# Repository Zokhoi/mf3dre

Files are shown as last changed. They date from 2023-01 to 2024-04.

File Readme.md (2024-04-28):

# Midi Fighter 3D Reverse Engineering
This repo holds the reverse engineered schematics and PCB design that should hopefully be functionally identical to the DJTechTools Midi Fighter 3D. This was done in the effort of creating functional firmware for the MF3D, as DJTechTools has shared or open sourced every Midi Fighter firmware except for MF3D.

The repository requires KiCAD v7.

However, there are also some components that I am not very certain about, which I hope would be uncovered as time goes by. In specific, the list of items are:
* the model of the LEDs
  * 4 white LEDs for bank buttons on top
  * 32 non-addressable RGB LEDs for arcade buttons

## Other details
Here are some of the other details that I have noticed while performing the reverse engineering.
* The button and RGB LED footprints are angled at 15 degrees.
* The pull up resistors R11 and R12 has pads on the PCB but are missing from the actual product. Maybe the chip doesn't actually need them?
* The through hole tactile switches SW23 and SW24 are not installed in the actual product. Presumably you can mount them on either side of the PCB.
* Both pin headers are not installed in the actual product.
* D17 is a chip with 5 internal diodes, and D18-21 are missing in the schematic, so the diodes in the chip were probably individually numbered in the original design.
* Resistor networks R5-7 are probably [CTS Electronic Components 746X101103JP](https://www.digikey.com/en/products/detail/cts-resistor-products/746X101103JP/1118406).
* The arcade button footprint has a test pad on the pulled up side, but I did not include it in the recreated footprint.
* The mounting screws are probably M3 screws.

In an email exchange with DJTT, they have stated that the magnometer IST8308 has been replaced by accelerometer MMA8453Q, but [both of these chips are present](./img/i2c%20cluster.png) on my board. In addition, the circuitry around IST8308 (U11) does not seem to correspond to the application circuit given in its datasheet.

## Previews
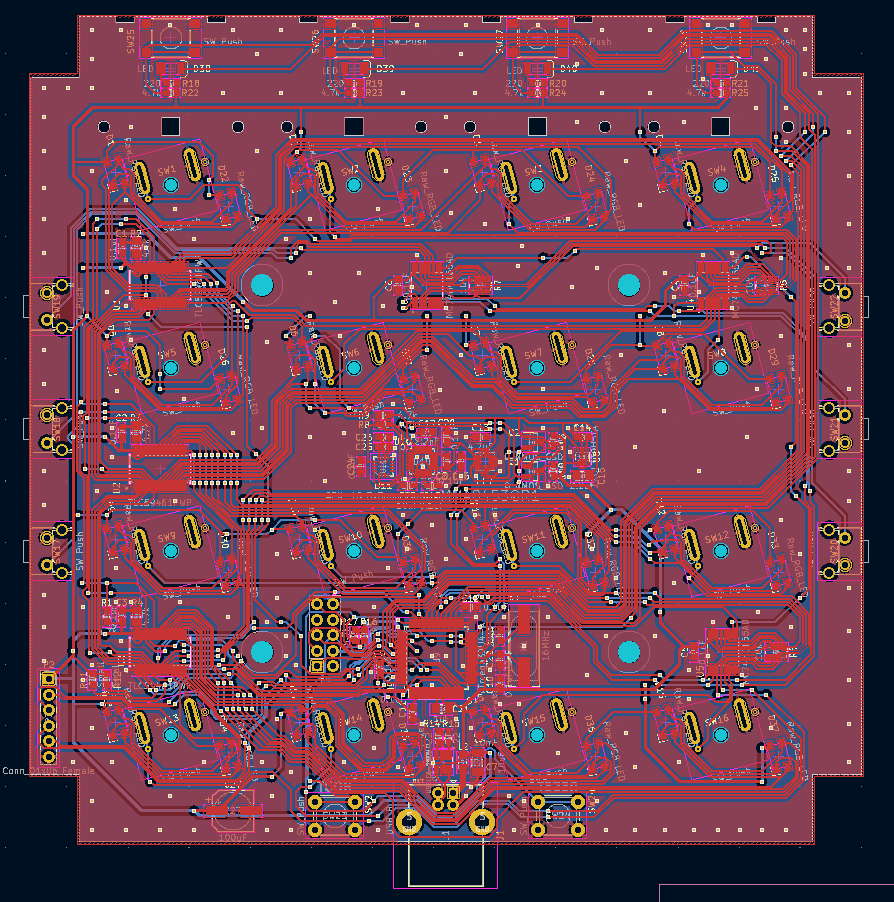
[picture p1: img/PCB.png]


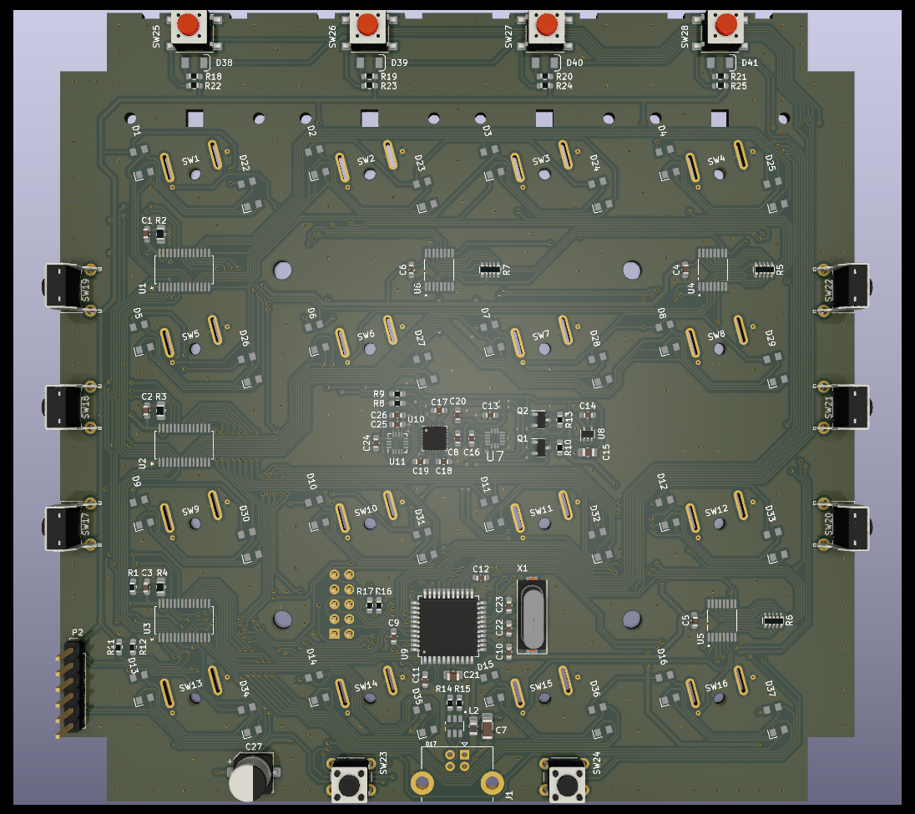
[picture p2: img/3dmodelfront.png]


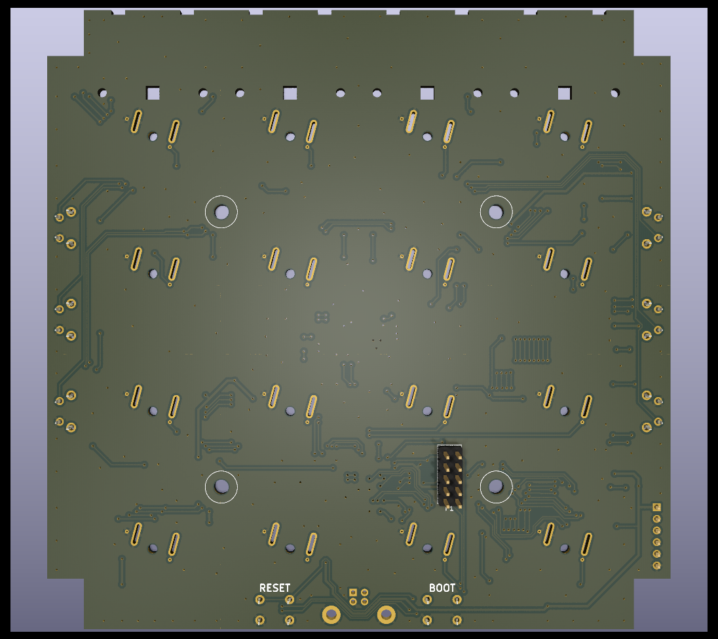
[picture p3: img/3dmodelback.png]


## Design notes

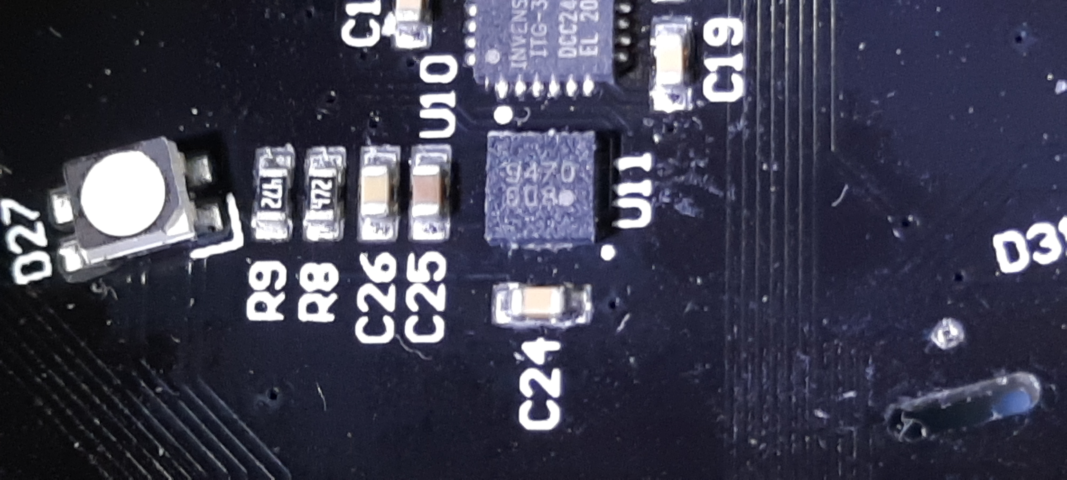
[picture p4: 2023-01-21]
img/U11.jpg

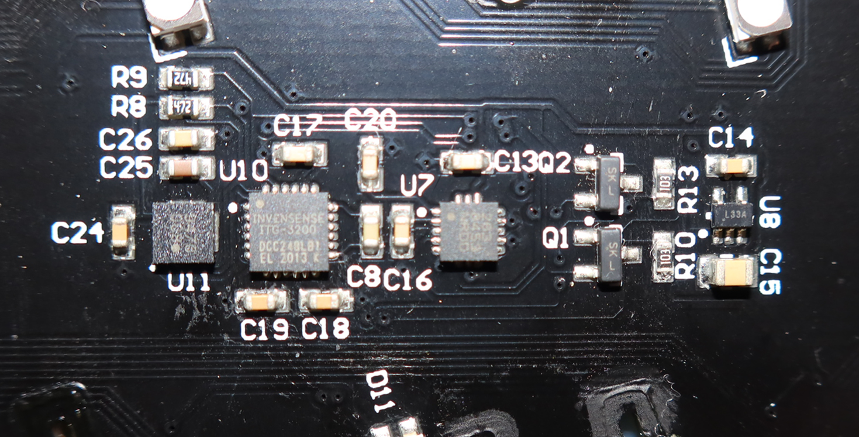
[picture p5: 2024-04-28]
img/i2c cluster.png

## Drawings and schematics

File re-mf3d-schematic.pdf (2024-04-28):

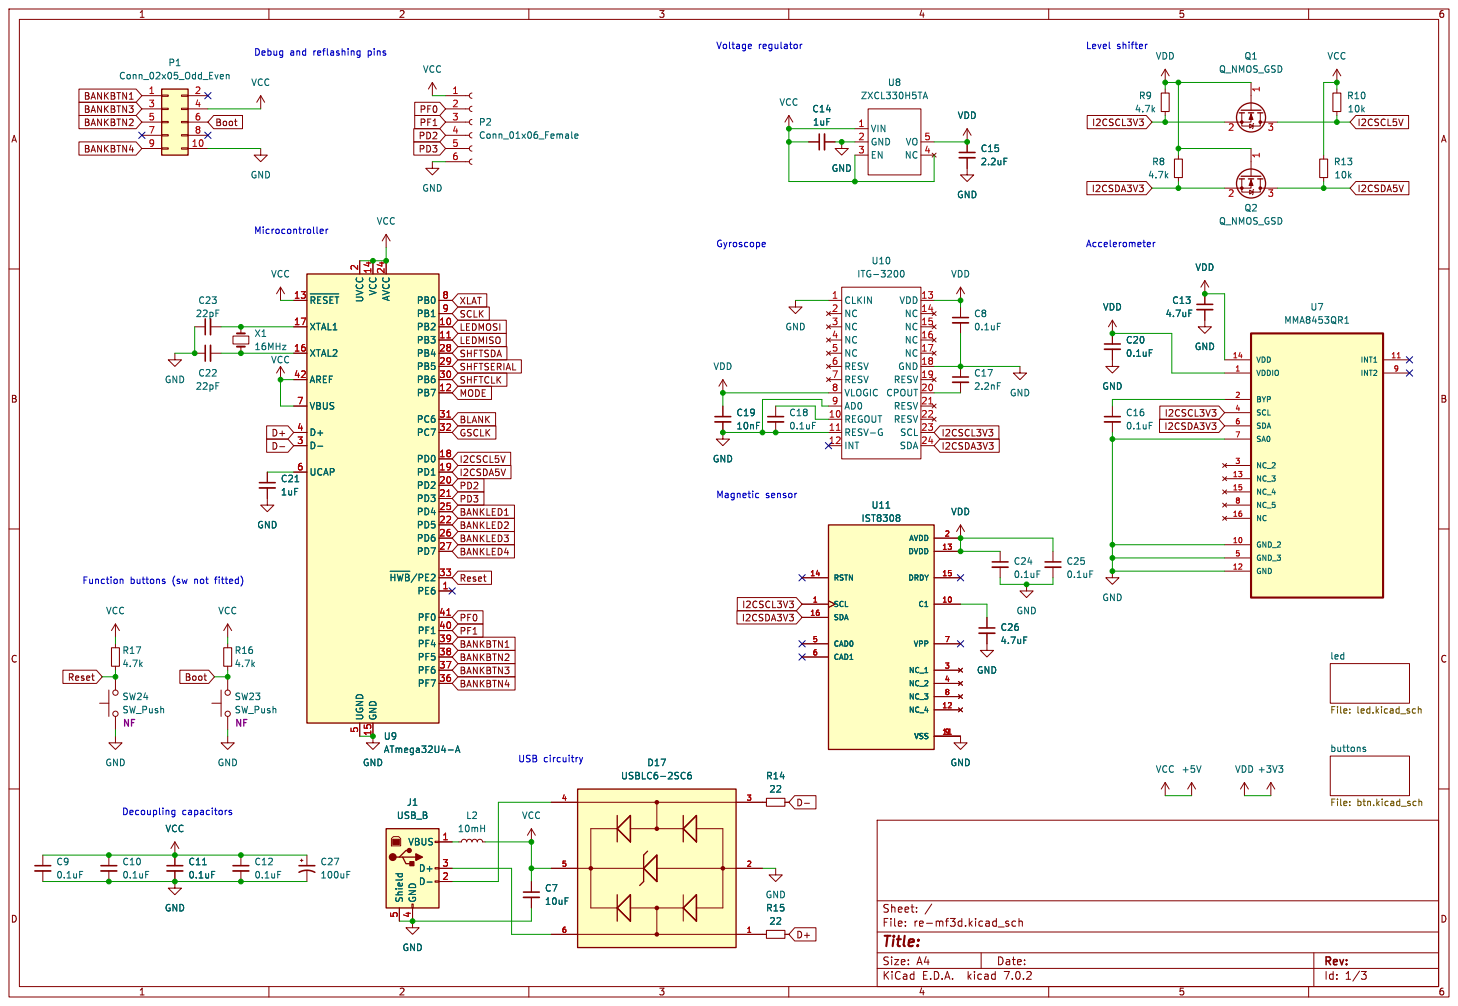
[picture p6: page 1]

Magnetic sensor USB circuitry

Id: 1/3 Title: File: re-mf3d.kicad_sch Sheet: /

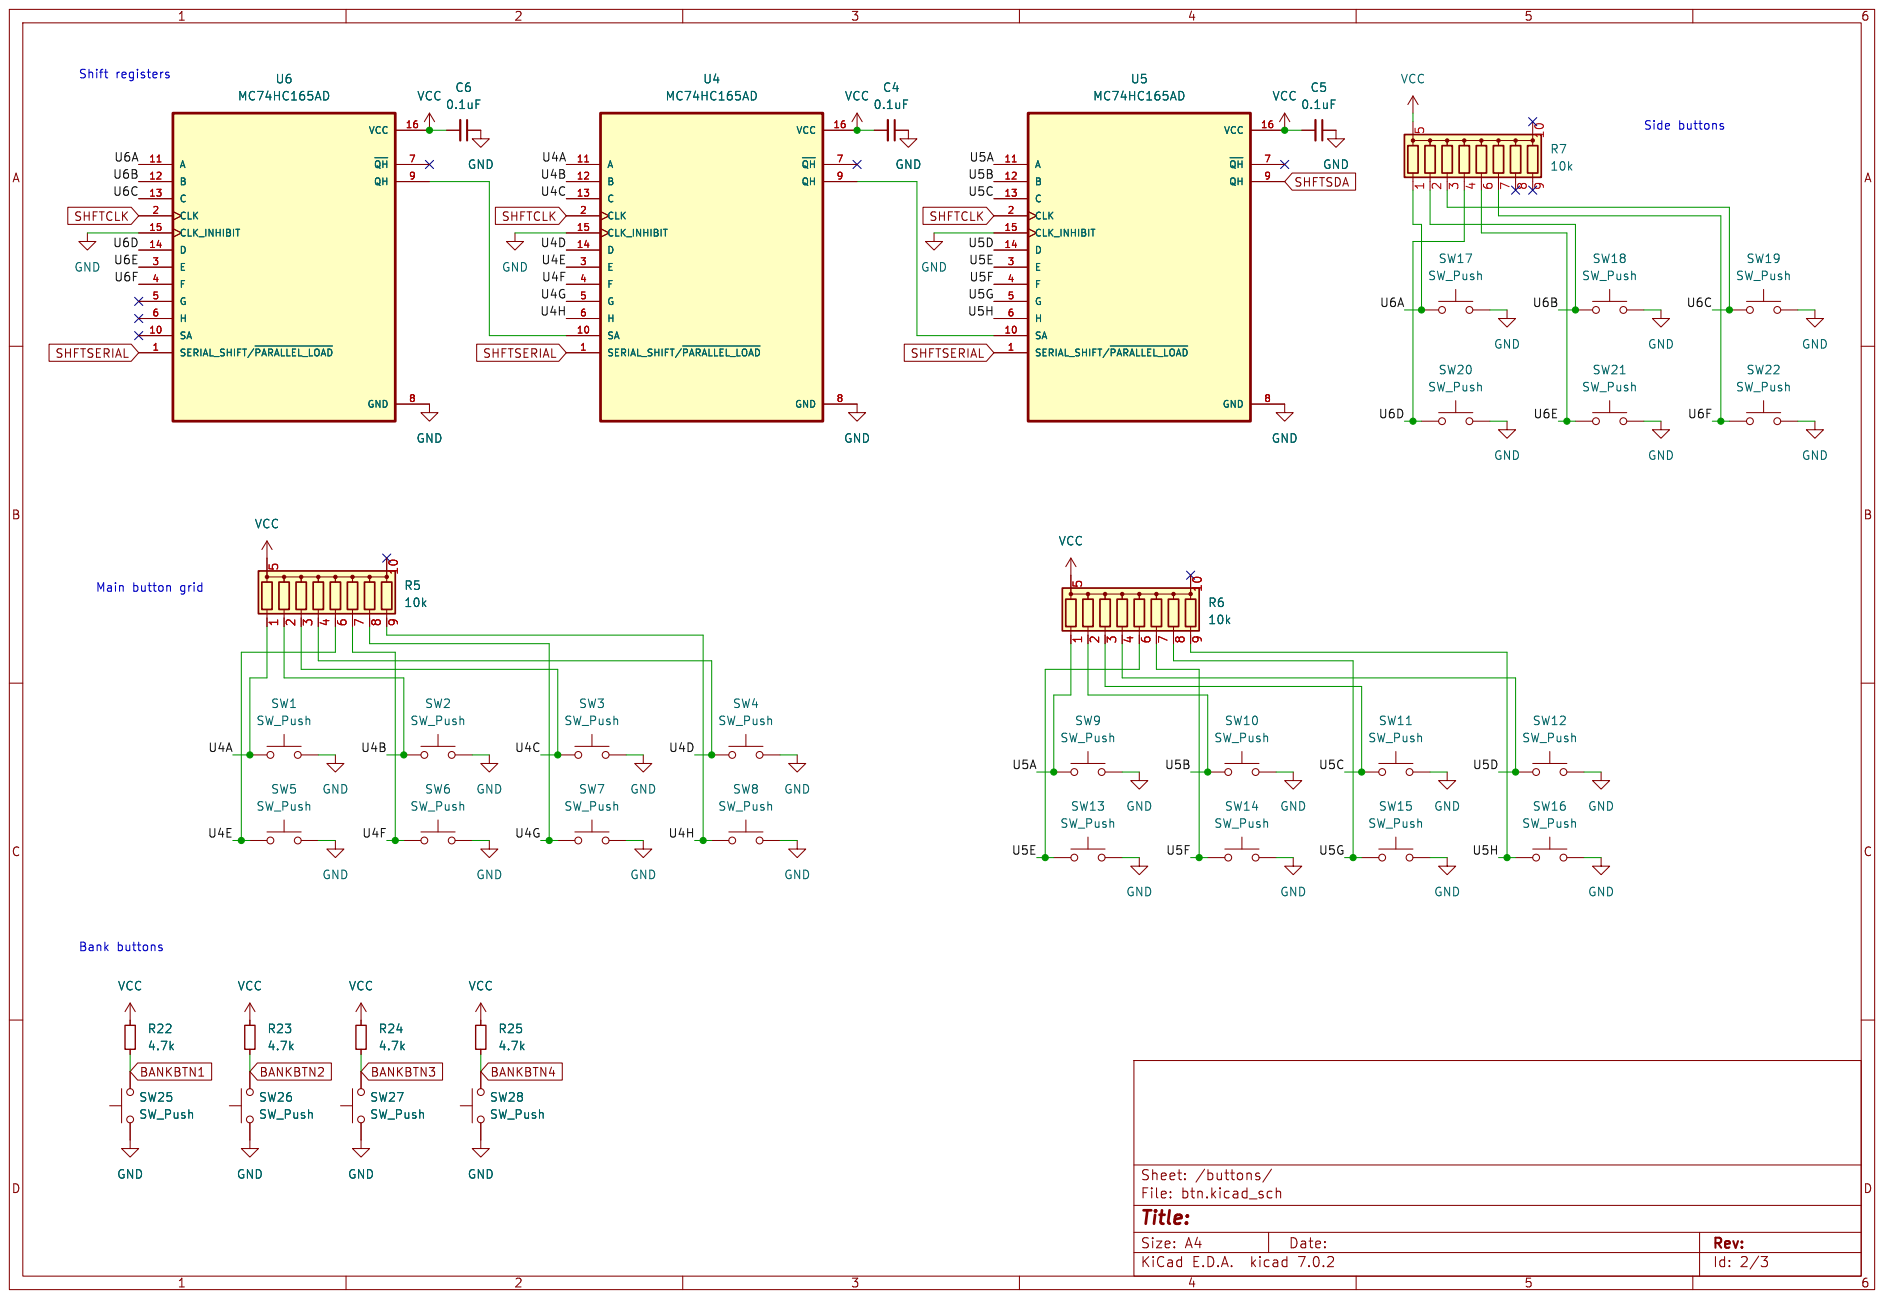
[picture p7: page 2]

Shift registers Main button grid VCC

Side buttons Bank buttons

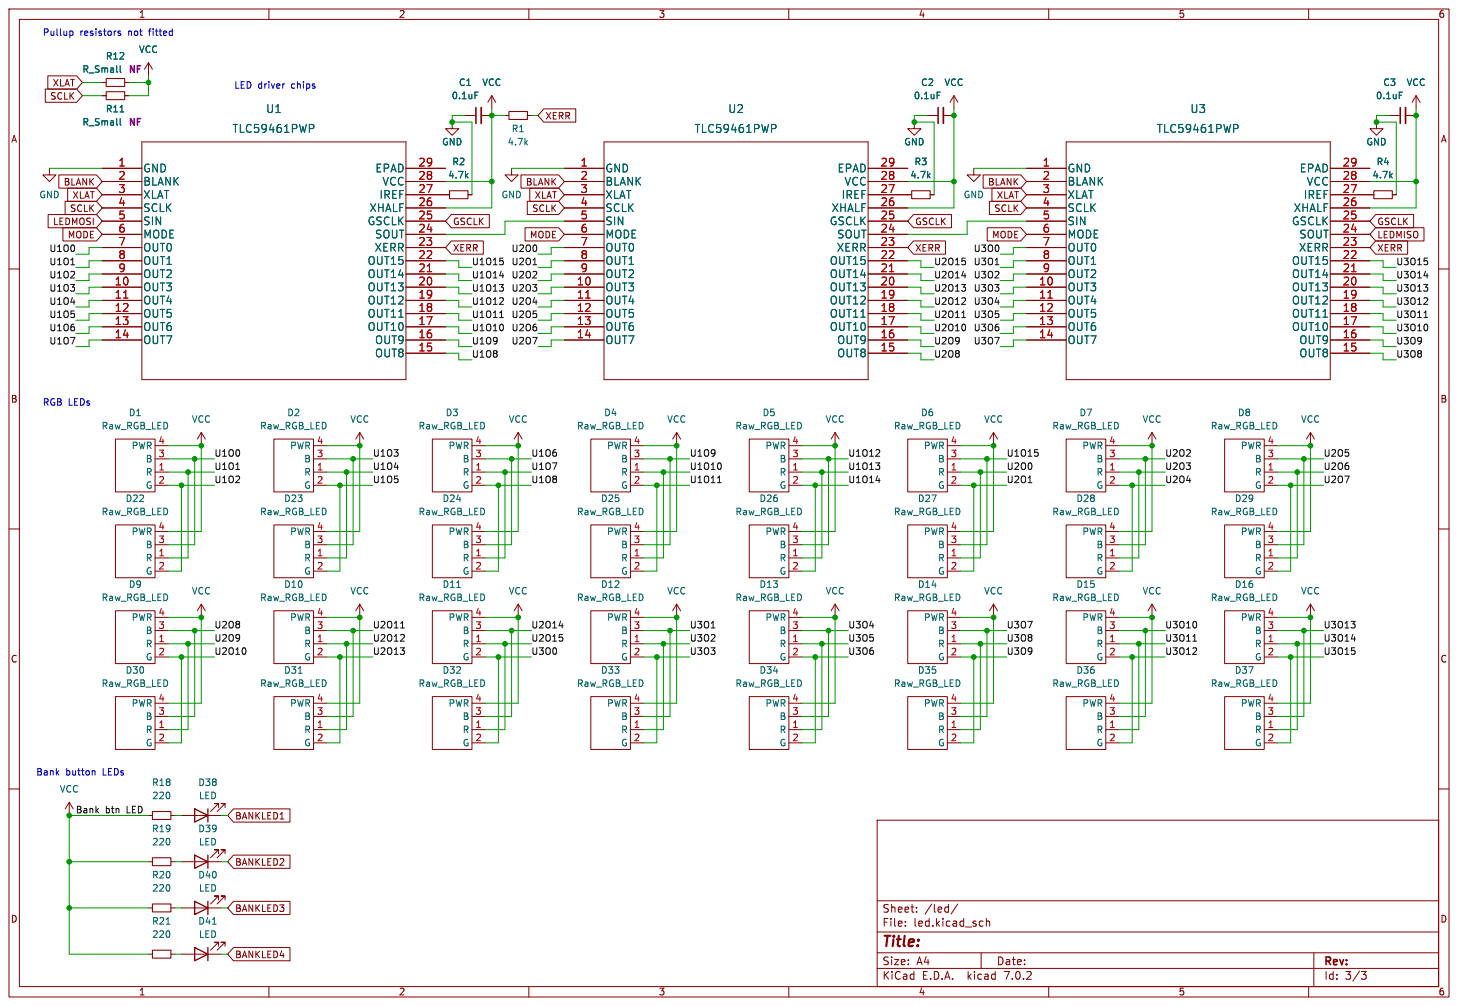
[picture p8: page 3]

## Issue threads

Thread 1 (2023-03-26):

Can you upload bootloader and firmware on it?

DRCRecoveryData, 2023-03-26:
Hi,

If we made new pcb does it work on original firmware?

Zokhoi, 2023-03-27:
That's what I'm hoping to achieve yes. However as the README has mentioned there are still some issues that can't be overlooked, even if you could get all the exact components right by transferring them from a working board. In specific, the issues are:
* the chip U11 and its related traces
* the footprint for the resistor networks R5, R6 and R7
Other than these, if you source new components, the capacitors and inductor values and led models are a problem too.

DRCRecoveryData, 2024-04-05:
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

Can you open request to djtechtools:

support@djtechtools.com

to get the stock firmware upload file of midi fighter 3d via icsp pinout?

i have request them like this:

Hi,

I have set fuses wrong of midi fighter 64 via icsp port

I use avrduress and forgot to set fuses to 00 so can't detect again the atmega32u4

Should i buy new atmega32u4 chip and flash new bootloader and firmware?

I need your guide and bootloader & firmware & fuses bit value setting
to repair it

and they sent firmware file and tutorial upload by:

Setup
1. Instal WinAVR (avrdude)
2. Instal Drivers for the USBTiny Pocket Programmer
3. Set slide switch on the USB Pocket Programmer to "No Power"
4. Open Command Prompt, type "avrdude". You should see the version and the options listed

Uploading HEX
1. Connect the MF64_V3 PCB to the PC with a USB cable
2. Connect the USB Pocket Programmer as shown in the picture
3. Make sure all the programing pins are in contact with the PCB. You can put a little pressure on the programmer cable with your thumb to ensure a good connection.
4. Double click "AVRDude - Upload HEX.bat"
5. HEX will upload, LED's will cycle RED, GREEN, BLUE. All LED's should be lit, on all colors.
6. Remove the 6 pin programming header
7. Remove the MF64_V3 PCB USB connection

Possible Errors:
1. If USBTiny cannot be found when uploading HEX, unplug and replug the USBTiny Pocket Programmer

maybe you can help to request they sent stock file :))

Zokhoi, 2024-04-05:
If you have midifighter utility installed, I think you can find the mf3d firmware binary in the internal files.

I have previously sent a support ticket asking for mf3d firmware source code, they replied they did not have plans to release the source code at the time though.

DRCRecoveryData, 2024-04-05:
> If you have midifighter utility installed, I think you can find the mf3d firmware binary in the internal files.
>
> I have previously sent a support ticket asking for mf3d firmware source code, they replied they did not have plans to release the source code at the time though.

No,

Just ask they new reuqest like me to get the bootloader and fw files because factory they have them, do you use discord telegram or any platform i wanna contact you

Zokhoi, 2024-04-05:
My discord is same as my username.

DRCRecoveryData, 2024-04-09:
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

U11 is IST8308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

Closed 2024-06-01.

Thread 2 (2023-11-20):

Custom Firmware

BoukeG, 2023-11-20:
In relation to writing the default firmware - have you been able to write some custom firmware?

Zokhoi, 2023-11-20:
I haven't gotten around to that unfortunately. However some other Midi Fighter models have their firmware source code available, so you might want to reference those as your starting point.

My personal suggestion is to start by looking at [Midi Fighter 64](https://github.com/wunnation/Midi_Fighter_64) which has the same MCU, but no devices on the I2C bus. Older 16-button Midi Fighters source code [are also available](https://github.com/DJ-TechTools), but no spectra source code.

BoukeG, 2023-11-20:
Cool, thanks - I'll have a look.

Closed 2023-11-20.

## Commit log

2023-04-23 Added some ground fills
    [re-mf3d.kicad_pcb, re-mf3d.kicad_sch]
2024-04-28 Migrate to kicad7 and component updates
    [btn.kicad_sch, led.kicad_sch, re-mf3d.kicad_pcb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]
